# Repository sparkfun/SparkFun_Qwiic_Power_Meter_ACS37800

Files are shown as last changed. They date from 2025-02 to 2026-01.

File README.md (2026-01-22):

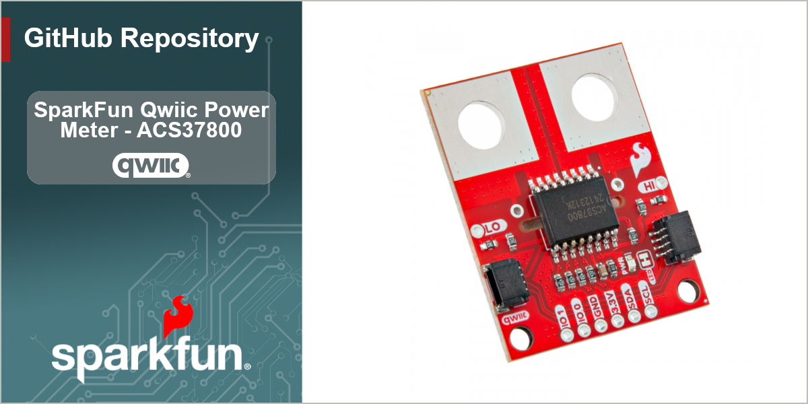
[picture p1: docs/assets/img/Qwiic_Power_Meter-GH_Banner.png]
SparkFun Qwiic Power Meter - ACS37800 (https://www.sparkfun.com/sparkfun-power-meter-acs37800-qwiic.html)


-----------------------------

The SparkFun Qwiic Power Meter - ACS37800 lets you measure voltage up to 60VDC and current up to &plusmn;30A over I<sup>2</sup>C. This board features the ACS37800 power monitor IC from Allegro Microsystems which uses a hall-effect, galvanically isolated current sensing technology to achieve reinforced isolation ratings on a small board footprint. This breakout integrates the ACS37800 into the Qwiic ecosystem to easily communicate over I<sup>2</sup>C. 

Although the ACS37800 power monitoring IC is capable of monitoring AC power at high line voltages, the SparkFun Qwiic Power Meter is designed for Safety Extra Low Voltage (SELV) applications of up to 60VDC only. Its use in AC power systems is not recommended.

Repository Contents
-------------------

* **/docs** - Hookup Guide files
* **/Hardware** - Eagle design files (.brd, .sch)
* **/Production** - Production panel files (.brd)

Documentation
--------------
* **[Library](https://github.com/sparkfun/SparkFun_ACS37800_Power_Monitor_Arduino_Library)** - Arduino library for the SparkFun Qwiic Power Meter - ACS37800.
* **[Hookup Guide](https://docs.sparkfun.com/SparkFun_Qwiic_Power_Meter_ACS37800)** - Basic hookup guide for the SparkFun Qwiic Power Meter - ACS37800.

Product Versions
----------------
* [SPX-17873](https://www.sparkfun.com/sparkx-power-meter-acs37800-qwiic.html) - Initial SparkX Release
* [SEN-29259](https://www.sparkfun.com/sparkfun-power-meter-acs37800-qwiic.html) - Initial SparkFun Release

License Information
-------------------

This product is _**open source**_! 

Please review the LICENSE.md file for license information. 

If you have any questions or concerns on licensing, please contact technical support on our [SparkFun forums](https://forum.sparkfun.com/viewforum.php?f=152).

Distributed as-is; no warranty is given.

- Your friends at SparkFun.

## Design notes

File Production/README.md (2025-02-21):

SparkFun <PRODUCT NAME> Production Files
=========================================

These are the production files SparkFun uses for printing PCBs.

License Information
-------------------
This product is open source! 

The hardware is released under [Creative Commons ShareAlike 4.0 International](https://creativecommons.org/licenses/by-sa/4.0/).

Please use, reuse, and modify these files as you see fit. Please maintain attribution to SparkFun Electronics and release anything derivative under the same license.

Distributed as-is; no warranty is given.

- Your friends at SparkFun.

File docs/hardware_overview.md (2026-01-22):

Let's take a closer look at the ACS37800 and the other hardware on the Qwiic Power Meter.

## ACS37800 Power Monitor IC

The ACS37800 power monitor IC from Allegro Microsystems is built around Allegro’s Hall-effect-based, galvanically isolated current sensing technology to achieve reinforced isolation ratings in a small PCB footprint. These features enable isolated current sensing without expensive Rogowski coils, oversized current transformers, isolated operational amplifiers, or the power loss of shunt resistors.

The ACS37800 power monitoring IC offers key power measurement parameters that can easily be accessed through its digital interface. Dedicated and configurable I/O pins for voltage/current zero crossing, undervoltage and overvoltage reporting, and fast overcurrent fault detection are available. User configuration of the IC - including its I2C address - is available through on-chip EEPROM. This breakout uses the <b>3.3V/30A</b> variant that communicates over I<sup>2</sup>C. Refer to the [datasheet](./assets/component_documentation/) for complete information about the ACS37800.

## Connectors

### Power Monitor Connections

This breakout has two large, isolated connections tied to the ACS37800's IP&plusmn; pins for connecting a voltage supply and load. The board also has smaller PTHs (plated through-holes) just below these large pads connected to IP&plusmn; if needed. 

The board routes the ACS37800's VINP and VINN to two PTHs. The ACS37800 can sense a maximum of &plusmn;250mV between VINP and VINN.

### Qwiic Connectors

The board's two Qwiic connectors route the I<sup>2</sup>C signals (SDA and SCL) along with 3.3V and Ground to both power the board and let it communicate over I<sup>2</sup>C.

### PTHs

The 0.1"-spaced PTH header on the bottom of the board routes out the ACS37800's VCC/3.3V, Ground, SDA, SCL and digital I/O pins (0 and 1). Refer to the "Configuring the DIO Pins" section in the [datasheet](./assets/component_documentation/) for more information about using these pins in I<sup>2</sup>C applications.

## LED

The sole LED on this board is a red Power LED to indicate when the board is powered on.

## Solder Jumpers

The Qwiic Power Meter has four solder jumpers labeled <b>IP+</b>, <b>I</sup>2</sup>C</b>, <b>LED</b> and <b>VINN</b>. The list below outlines their functionality, default states and notes on how to use them.

* <b>IP+</b> - This jumper connects the IP+ pin to the voltage divider on the board and is CLOSED by default. Opening this jumper isolates the "top" of the resistor divider from the IP+ power pad. Advanced users can open this jumper to measure current on the low side (and voltage from the high side).
* <b>I<sup>2</sup>C</b> - This three-way jumper pulls the SDA and SCL lines to <b>3.3V</b> through a pair of <b>4.7k&ohm;</b> resistors. It is CLOSED by default. Open the jumper to disable pullups on the I<sup>2</sup>C bus if necessary.
* <b>LED</b> - This jumper completes the circuit for the red Power LED. It is CLOSED by default. Open this jumper to disable the Power LED.
* <b>VINN</b> - This solder jumper connects the VINN pin to ground and is CLOSED by default. VINN **must** be connected to ground and this jumper should remain closed in most applications.

## Board Dimensions

The Qwiic Power Meter Breakout - ACS37800 is slightly larger than the standard Qwiic breakout and measures 1.2" x 1.5" (30.48mm x 38.10mm) with a pair of mounting holes that fit a 4-40 screw. 

<figure markdown>
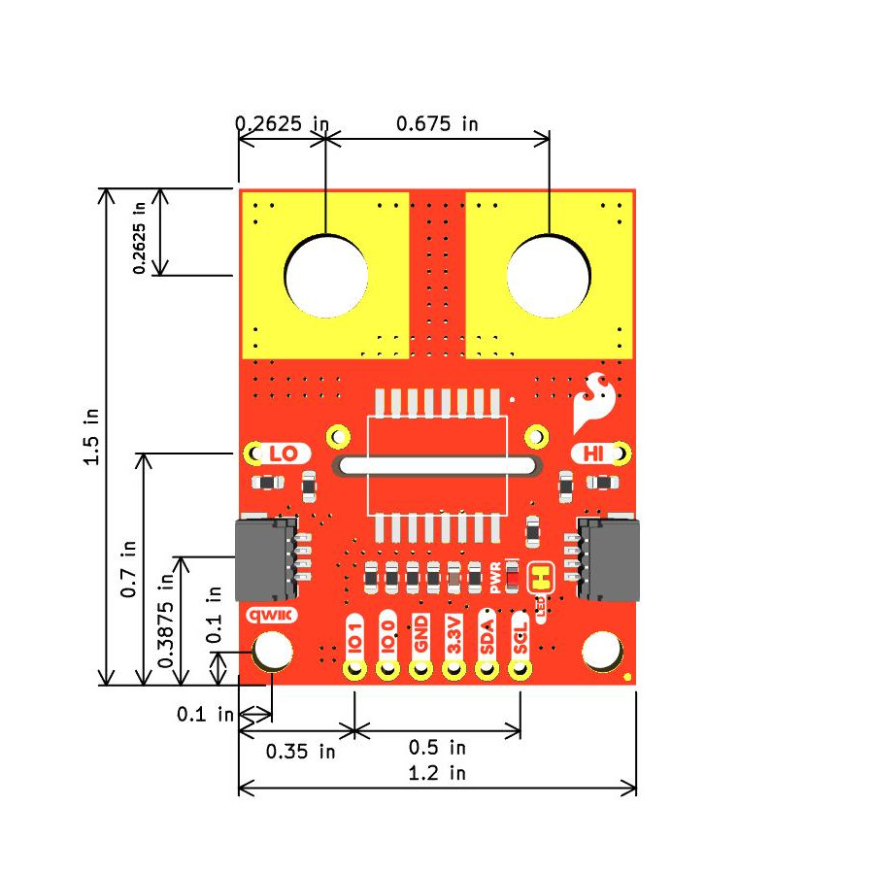
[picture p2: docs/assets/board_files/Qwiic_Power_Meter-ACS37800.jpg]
Board dimensions

</figure>

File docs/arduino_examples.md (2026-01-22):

Let's take a look at a few of the examples included in the SparkFun ACS37800 Power Monitor library.

## Example 1 - Read Voltage, Current, Power

The first example is a basic example that enables the Qwiic Power Meter and prints out measured values for voltage (Volts), current (Amps) and power (Watts). Open the example by navigating to **File** > **Examples** > **SparkFun ACS37800 Power Monitor Arduino Library** > **Example1_ReadVoltageCurrentPower**. Select your Board and Port and click the upload button. Once the code finishes compiling and uploading, open the [serial monitor](https://docs.arduino.cc/software/ide-v2/tutorials/ide-v2-serial-monitor) with the baud set to **115200** and you should see values print out every 250ms for Volts, Amps and Watts. 

If you see "ACS37800 not detected. Check connections and I2C address. Freezing..." print out, check to make sure the Qwiic Power Meter is wired correctly and properly connected to your RedBoard. If values print out as all 0's, make sure the voltage source, load and RedBoard all share a common ground.

## Example 2 - Set I<sup>2</sup>C Address

The second example shows how to adjust the ACS37800's I<sup>2</sup>C address in the IC's EEPROM. The ACS37800 accepts any valid I<sup>2</sup>C address set in the definition for `NEW_ADDRESS` in the line below:

``` c++
#define NEW_ADDRESS 0x60
```

Adjust the value for `NEW_ADDRESS` if needed and then click the "Upload" button. After the code finishes uploading, open the serial monitor with the baud set to **115200** and follow the prompts to complete the address change.

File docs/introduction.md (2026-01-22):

<figure markdown>
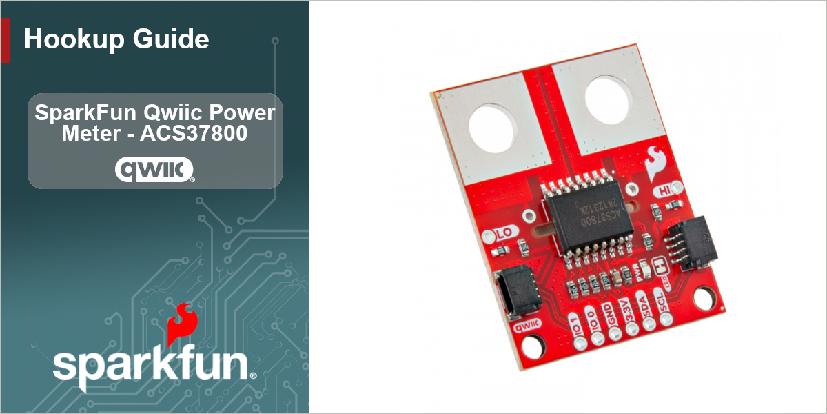
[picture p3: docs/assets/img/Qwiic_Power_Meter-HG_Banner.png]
Qwiic Power Meter Hookup Guide banner image (https://www.sparkfun.com/sparkfun-power-meter-acs37800-qwiic.html)

</figure>

The SparkFun Qwiic Power Meter - ACS37800 lets you measure voltage up to 60VDC and current up to &plusmn;30A over I<sup>2</sup>C. This board features the ACS37800 power monitor IC from Allegro Microsystems which uses a hall-effect, galvanically isolated current sensing technology to achieve reinforced isolation ratings on a small board footprint.

In order to follow along with this guide you'll need the SparkFun Qwiic Power Meter along with the following items:

* [SparkFun RedBoard IoT - ESP32](https://www.sparkfun.com/sparkfun-iot-redboard-esp32-development-board.html) (or other Arduino development board)
* [USB-C Cable](https://www.sparkfun.com/usb-a-to-usb-c-cable-1m-usb-2-0-flexible-silicone.html)
* [Qwiic Cable](https://www.sparkfun.com/flexible-qwiic-cable-100mm.html)
* A device to monitor current or voltage.

You'll also need a soldering iron and solder to wire the Qwiic Power Meter to the device you're monitoring. If you need either of those items, we have a selection of them available in our [Soldering category](https://www.sparkfun.com/tools/soldering.html).

## Topics Covered

This document contains three main sections: **Quick Start Guide**, **Hardware** and **Software**.

The Quickstart Guide assumes a working knowledge of how to assemble and use Qwiic breakouts, perform through-hole soldering, measuring current in series and using the Arduino IDE. It demonstrates how to wire up the Qwiic Power Meter to measure current in series and then jumps right into getting the necessary software packages installed to start uploading code in just a few short minutes.

The Hardware pages include a hardware overview that provides a detailed overview of the Qwiic Power Meter - ACS37800 covering all the major components on the board in detail as well as a hardware assembly page which goes over the steps required to assemble and use the board to measure current with a compatible Arduino development board.

The Software pages give instructions on how to install the SparkFun ACS37800 Arduino Library and use some of the examples included in it.

## Resources and Documentation

You'll find the board design files (KiCad files & schematic), relevant documentation (datasheets, white papers, etc.) and other helpful links in the **Resources** tab. Lastly, the **Support** pages include a Troubleshooting page that includes any helpful tips specific to this board as well as information on how to receive technical support from SparkFun.

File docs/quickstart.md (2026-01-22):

In this Quick Start guide we'll demonstrate how to assemble and use the Qwiic Power Meter to measure voltage, current and power using the SparkFun ACS37800 Power Monitor Arduino Library. This guide assumes you have an understanding of measuring current, using Qwiic breakouts and the Arduino IDE. If you're not familiar with any of these concepts we recommend reading through the Hardware and Software sections of this guide as they provide more thorough information about this Qwiic breakout and how to use it with Arduino.

## Power Monitoring Demo Assembly

### Voltage Supply and Load Assembly

We'll start by connecting the Qwiic Power Meter to our voltage supply and load. For this demo, we're using a 10 Watt power resistor to simulate the load but the concepts and circuit design can be applied to an actual power monitor circuit for something like a 3D printer or motor. Make sure to leave the load circuit powered OFF before completing the assembly to avoid damaging anything. Since we're measuring power in series we'll need to interrupt the voltage supply going to the power resistor by completing the following steps:

* Connect the the voltage supply to the IP+ pin.
* Connect the power resistor or "load" to the IP- pin.
* Connect the load to ground. In the case of this demo, we've connected the opposite side of the power resistor to the ground rail on our breadboard so we can create a common ground with the RedBoard IoT next.

<figure markdown>
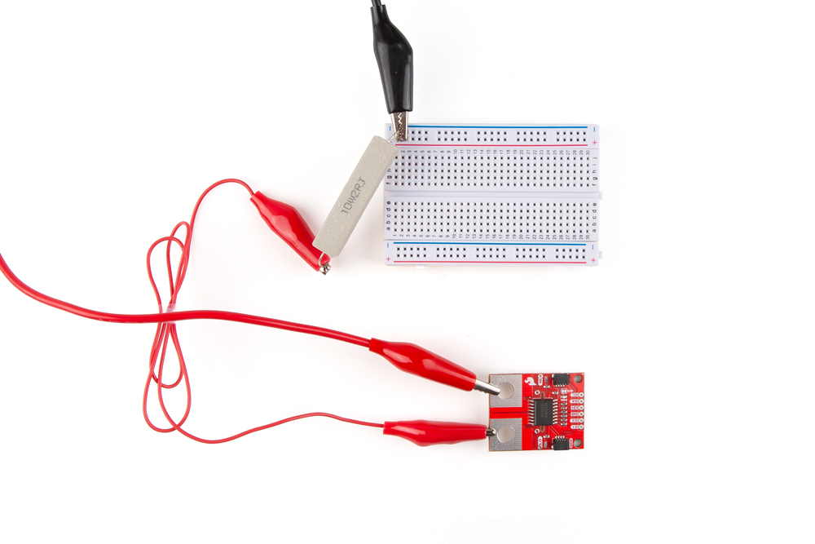
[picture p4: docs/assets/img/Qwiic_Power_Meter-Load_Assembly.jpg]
Voltage supply and load circuit assembled

</figure>

### Qwiic Assembly

Next we'll connect the Qwiic Power Meter to the RedBoard IoT - ESP32. 

* Connect the two boards together using a Qwiic cable.
* Create a connection between the grounds of the voltage source, Qwiic Power Meter and RedBoard. Since this connection is a low current path and we're using a breadboard and power resistor for this demo, we just need to connect the breadboard's ground rail to a ground pin on the RedBoard IoT using a jumper wire.
* Connect the RedBoard to a computer over USB.

The completed demo circuit should look similar to the photo below:

<figure markdown>
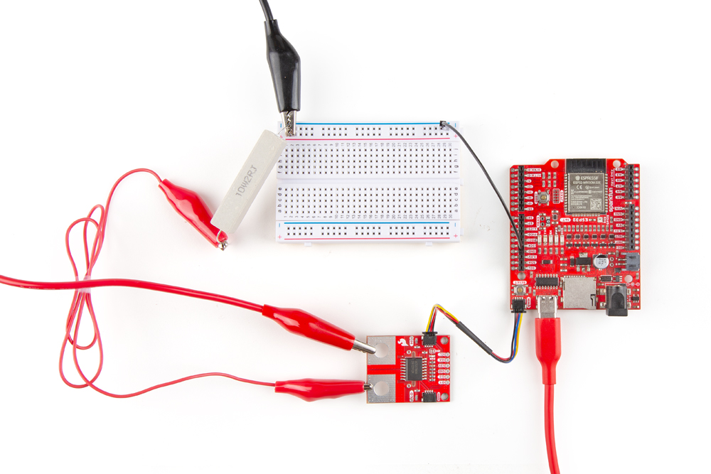
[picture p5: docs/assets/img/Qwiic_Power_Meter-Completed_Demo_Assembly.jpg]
Completed demo circuit

</figure>

## Arduino Example

With the power meter circuit built, let's move on to uploading code to monitor it.

* Install the SparkFun ACS37800 Power Monitor Arduino library using the [library manager](https://docs.arduino.cc/software/ide-v2/tutorials/ide-v2-installing-a-library/) by searching for "SparkFun ACS37800".
* If you don't already have the RedBoard IoT - ESP32 board definition installed, you'll need to install the "esp32" boards package by Espressif Systems. Copy this JSON URL: `https://espressif.github.io/arduino-esp32/package_esp32_dev_index.json` to the "Additional Boards Manager URLs" in the "Preferences" menu and then search for "esp32" in the [boards manager](https://docs.arduino.cc/software/ide-v2/tutorials/ide-v2-board-manager) tool and install the latest version of the "esp32 by Espressif Systems" boards package.
* Open Example 1 - Read Voltage Current Power.
* Select your Board and Port and click the "Upload" button.
* Once the code finishes uploading, open the serial monitor with the baud set to **15200** and you should see values for Volts, Amps and Watts print out every 250ms.

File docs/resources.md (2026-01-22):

Check out the resources below for more information about the SparkFun Qwiic Power Meter - ACS37800.

* [Schematic](./assets/board_files/Qwiic_Power_Meter-ACS37800.pdf)
* [KiCad Files](./assets/board_files/Qwiic_Power_Meter-ACS37800.zip)
* [Board Dimensions](./assets/board_files/Qwiic_Power_Meter-ACS37800.jpg)
* [Datasheet](./assets/component_documentation/ACS37800-Datasheet.pdf) (ACS37800)
* [SparkFun Arduino Library](https://github.com/sparkfun/SparkFun_ACS37800_Power_Monitor_Arduino_Library)
* [GitHub Repository](https://github.com/sparkfun/SparkFun_Qwiic_Power_Meter_ACS37800)

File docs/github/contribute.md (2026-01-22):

# Contribute: Make an Augmentation!
Spot an improvement opportunity? Feel free to contribute to our open-source design and documentation. 

## :material-file-document-multiple:&nbsp;Improve our Documentation
All of this documentation can be modified by you! Please help us make it better.

* These pages are contained in the [`docs` folder](https://github.com/sparkfun/SparkFun_Qwiic_Power_Meter_ACS37800/tree/main/docs) of the [SparkFun Qwiic Power Meter - ACS37800 repository](https://github.com/sparkfun/SparkFun_Qwiic_Power_Meter_ACS37800).

<!-- ### :material-source-pull:&nbsp;Submit a Correction -->
### Submit a Correction

1. With a GitHub account, [fork this repository](https://github.com/sparkfun/SparkFun_Qwiic_Power_Meter_ACS37800/fork).
2. Add your corrections or improvements to the markdown file.
3. File a pull request with your changes, and enjoy making the ~~words~~ ~~worlds~~ world a better place.
	* Once received, the documentation specialist will automatically be notified.
	* We will review your suggested improvements to make sure they are correct and fit within our documentation standards.

## :material-cog:&nbsp;Improve our Hardware Design
All of our designs are open-source! Please help us make it better.

* Our board design files are contained in the [`Hardware` folder](https://github.com/sparkfun/SparkFun_Qwiic_Power_Meter_ACS37800/tree/main/Hardware) of the [SparkFun Qwiic Power Meter - ACS37800 repository](https://github.com/sparkfun/SparkFun_Qwiic_Power_Meter_ACS37800).

<!-- ### :material-source-pull:&nbsp;Submit a Design Enhancement -->
### Submit a Design Enhancement

1. With a GitHub account, [fork this repository](https://github.com/sparkfun/SparkFun_Qwiic_Power_Meter_ACS37800/fork).
2. Add your design augmentation(s)
3. File a pull request with your changes, and enjoy making the ~~words~~ ~~worlds~~ world a better place.
	1. Once received, the engineer in charge of the original design will automatically be notified.
	2. We will review your suggested improvement(s) to verify that they are within our board design standards and meet our product design requirements.
	3. If approved, we will flag these changes for our next board revision. Congrats! 🍻

		!!! info
			Even if your suggestion is accepted, these changes may not be immediately available for purchase. We may have to cycle through our current product inventory first.

## Contributors&nbsp;:clap:
Let's provide some recognition to the contributors for this project!

GitHub Contributors Image
<br>


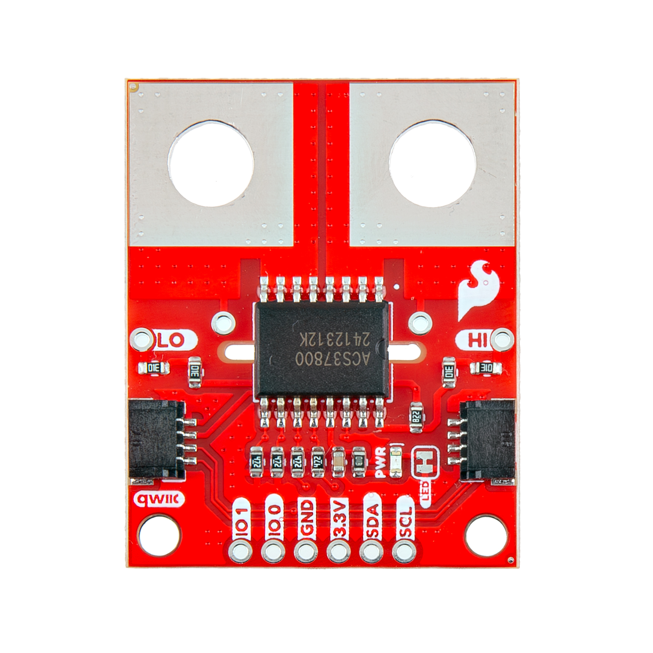
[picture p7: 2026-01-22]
docs/assets/img/Qwiic_Power_Meter-Front.jpg

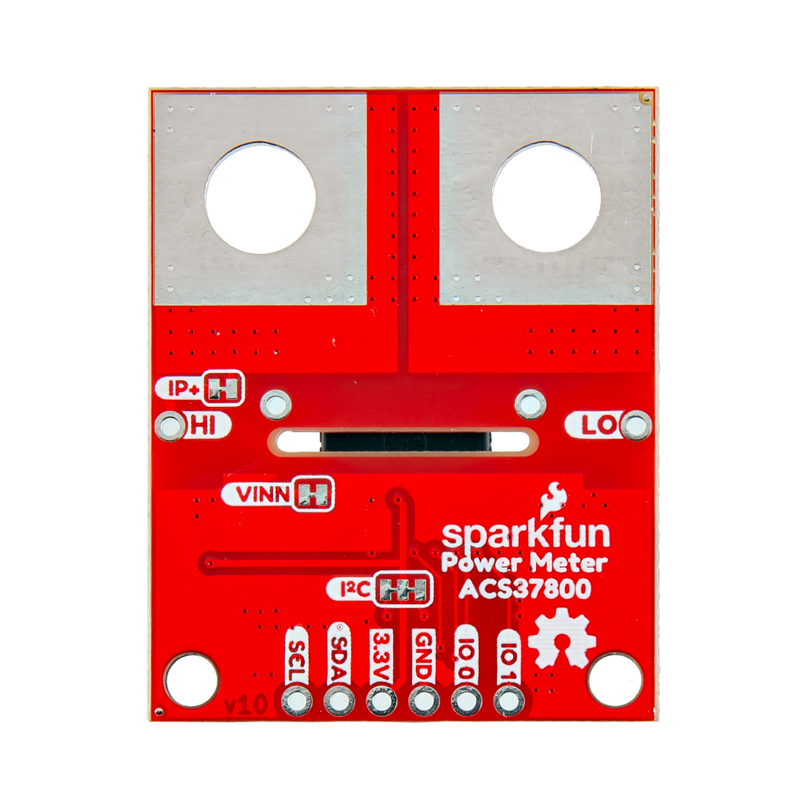
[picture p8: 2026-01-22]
docs/assets/img/Qwiic_Power_Meter-Back.jpg

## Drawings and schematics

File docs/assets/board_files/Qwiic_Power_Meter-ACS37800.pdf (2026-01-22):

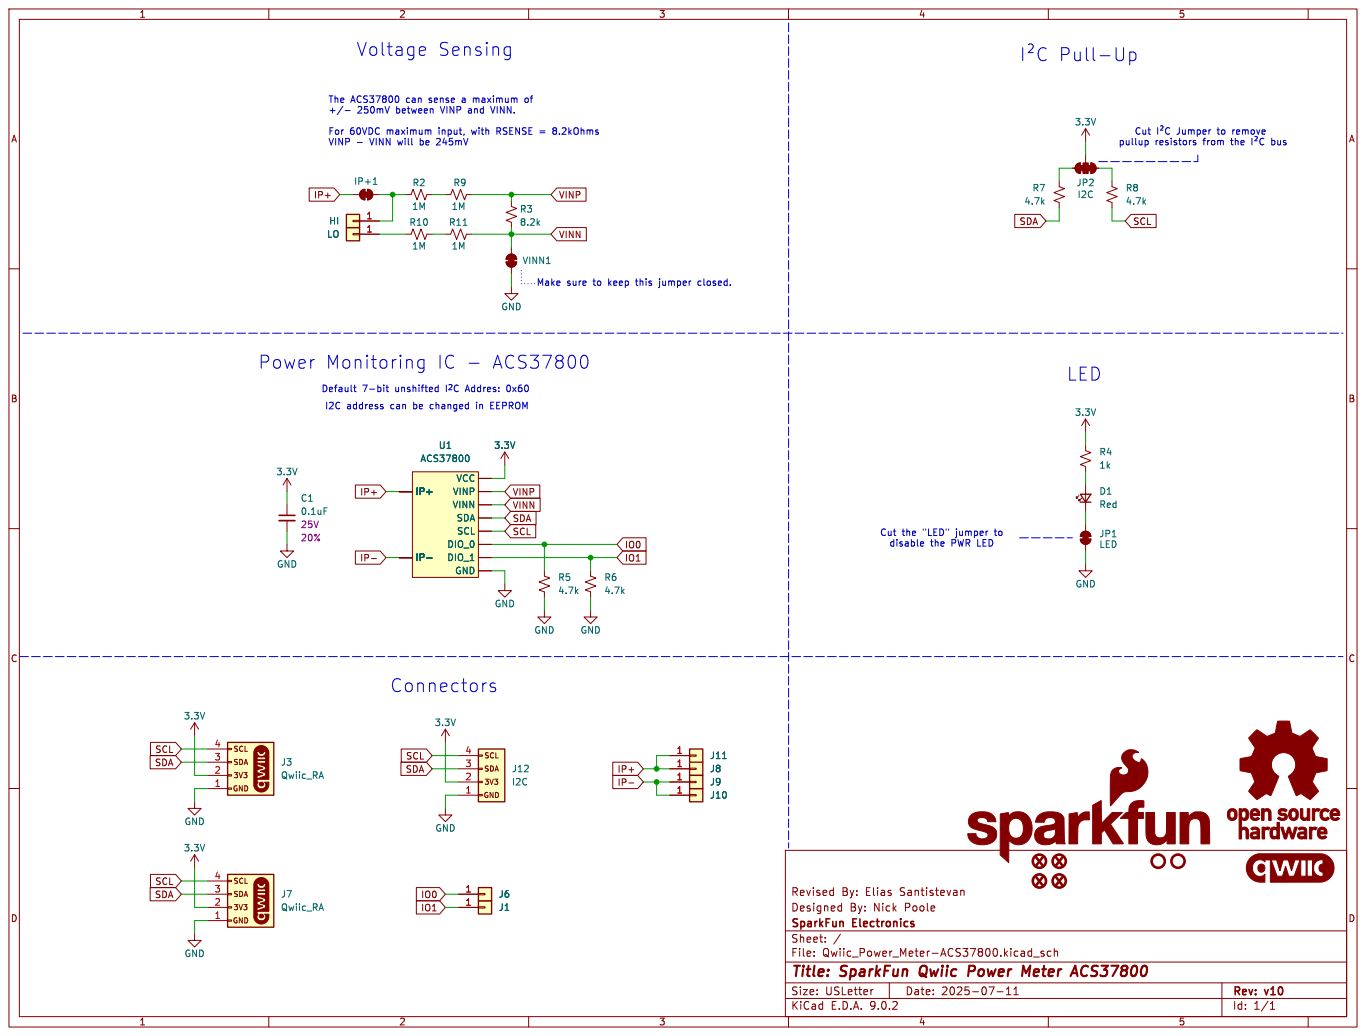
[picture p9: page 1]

disable the PWR LED Voltage Sensing

Cut þÿI²CJumper to remove

Make sure to keep this jumper closed. Connectors
J6 1 U1 ACS37800

I2C address can be changed in EEPROM

Cut the "LED" jumper to

Id: 1/1 Title: SparkFun Qwiic Power Meter ACS37800

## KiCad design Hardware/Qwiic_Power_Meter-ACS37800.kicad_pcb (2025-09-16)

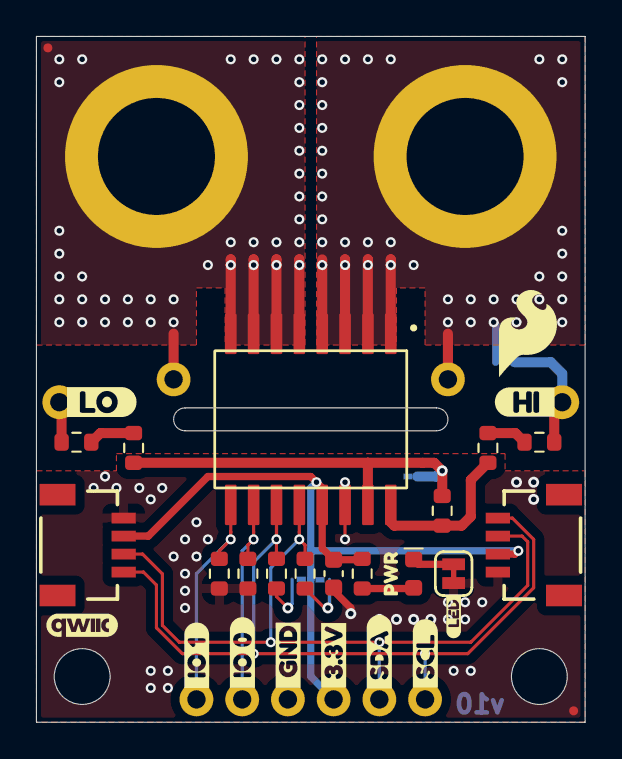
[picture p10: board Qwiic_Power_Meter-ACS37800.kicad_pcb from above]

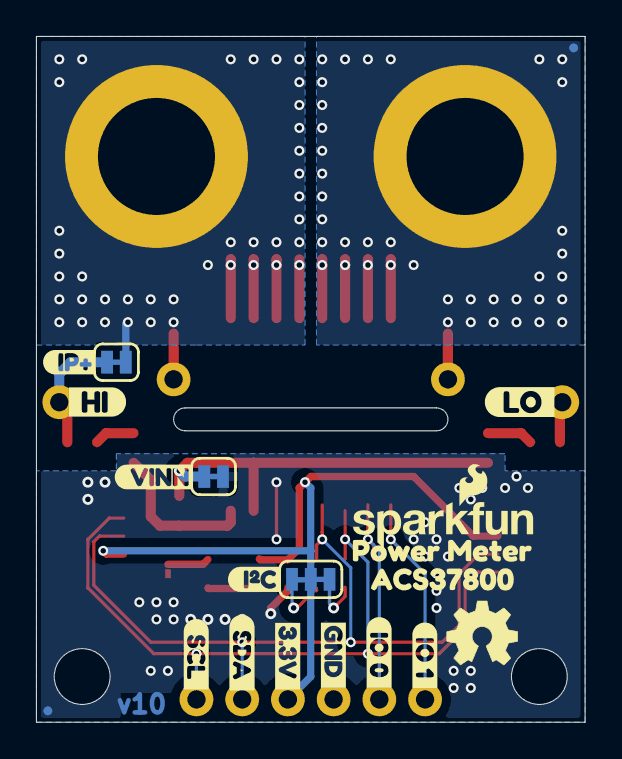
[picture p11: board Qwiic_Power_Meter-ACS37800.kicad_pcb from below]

Board: 2 copper layers, 30.5 x 38.1 mm, 59 parts (19 on the bottom side), 18 nets.

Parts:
C1: 0.1uF; C_0603_1608Metric
D1: Red; LED_0603_1608Metric_Red
FID1, FID2, FID3, FID4: Fiducial_0.5mm; Fiducial_0.5mm_Mask1mm
G1: OSHW_Logo; Creative_Commons_License
IP+1: Jumper_2_NC_Trace
J1, J4, J5, J6, J10, J11: Conn_01x01; 1x01
J3, J7: Qwiic_RA; JST_SMD_1.0mm-4_Black
J8, J9: Conn_01x01; 1x01_0.4in
J12: I2C; 1x04
JP1: LED; Jumper_2_NC_Trace
JP2: I2C; Jumper_3_NC-2_Trace
R2, R9, R10, R11: 1M; R_0603_1608Metric
R3: 8.2k; R_0603_1608Metric
R4: 1k; R_0603_1608Metric
R5, R6, R7, R8: 4.7k; R_0603_1608Metric
Ref**: Val**; OSHW_Logo_4mm
ST1, ST2: Standoff
U1: ACS37800; SO-16_Wide_Power
VINN1: Jumper_2_NC_Trace
kibuzzard-67B80BA2: G***; kibuzzard-67B80BA2
kibuzzard-68C98CE2: G***; kibuzzard-68C98CE2
kibuzzard-68C98CF7: G***; kibuzzard-68C98CF7
kibuzzard-68C98D0A: G***; kibuzzard-68C98D0A
kibuzzard-68C98D92: G***; kibuzzard-68C98D92
kibuzzard-68C98DAC: G***; kibuzzard-68C98DAC
kibuzzard-68C98DC2: G***; kibuzzard-68C98DC2
kibuzzard-68C98DD6: G***; kibuzzard-68C98DD6
kibuzzard-68C98DF7: G***; kibuzzard-68C98DF7
kibuzzard-68C98E17: G***; kibuzzard-68C98E17
kibuzzard-68C98F03: G***; kibuzzard-68C98F03
kibuzzard-68C98FF6: G***; kibuzzard-68C98FF6
kibuzzard-68C9901D: G***; kibuzzard-68C9901D
kibuzzard-68C9907C: G***; kibuzzard-68C9907C
kibuzzard-68C9913E: G***; kibuzzard-68C9913E
kibuzzard-68C9961E: G***; kibuzzard-68C9961E
kibuzzard-68C99001: G***; kibuzzard-68C99001
kibuzzard-68C99018: G***; kibuzzard-68C99018
kibuzzard-68C99023: G***; kibuzzard-68C99023
kibuzzard-68C99027: G***; kibuzzard-68C99027
kibuzzard-68C99085: G***; kibuzzard-68C99085
kibuzzard-68C99129: G***; kibuzzard-68C99129
kibuzzard-68C99652: G***; kibuzzard-68C99652

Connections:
3.3V: C1.1, J3.2, J7.2, J12.2, JP2.2 (B), R4.1, U1.13 (VCC)
GND: C1.2, J3.1, J7.1, J12.1, JP1.1 (A), R5.1, R6.1, U1.14 (GND), VINN1.2 (B)
IO0: J6.1, R5.2, U1.10 (DIO_0)
IO1: J1.1, R6.2, U1.9 (DIO_1)
IP+: IP+1.2 (B), J8.1, J11.1, U1.1 (IP+), U1.2 (IP+), U1.3 (IP+), U1.4 (IP+)
IP-: J9.1, J10.1, U1.5 (IP-), U1.6 (IP-), U1.7 (IP-), U1.8 (IP-)
unnamed: D1.2 (A), R4.2
unnamed: D1.1 (K), JP1.2 (B)
unnamed: IP+1.1 (A), J4.1, R2.1
unnamed: J5.1, R10.1
unnamed: JP2.1 (A), R8.2
unnamed: JP2.3 (C), R7.2
unnamed: R2.2, R9.1
unnamed: R10.2, R11.1
SCL: J3.4, J7.4, J12.4, R8.1, U1.11 (SCL)
SDA: J3.3, J7.3, J12.3, R7.1, U1.12 (SDA)
VINN: R3.1, R11.2, U1.15 (VINN), VINN1.1 (A)
VINP: R3.2, R9.2, U1.16 (VINP)

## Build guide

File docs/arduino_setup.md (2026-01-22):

!!! arduino
    If this is your first time using the Arduino IDE, Arduino libraries or board add-ons, we recommend reading through the following tutorials:

    - [Installing the Arduino IDE](https://learn.sparkfun.com/tutorials/installing-arduino-ide)
    - [Installing an Arduino Library](https://learn.sparkfun.com/tutorials/installing-an-arduino-library)
    - [Installing Board Definitions in the Arduino IDE](https://learn.sparkfun.com/tutorials/installing-board-definitions-in-the-arduino-ide)

## SparkFun ACS37800 Power Monitor Arduino Library

The SparkFun ACS37800 Power Monitor Arduino Library is a simple library to configure and use the ACS37800 over I<sup>2</sup>C. You can install the library with the Arduino [Library manager](https://docs.arduino.cc/software/ide-v2/tutorials/ide-v2-installing-a-library/) tool by searching for "SparkFun ACS37800". If you'd prefer a manual install, you can download a ZIP of the library [here](https://github.com/sparkfun/SparkFun_ACS37800_Power_Monitor_Arduino_Library/archive/refs/heads/main.zip).

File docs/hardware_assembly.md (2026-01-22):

Now that we're familiar with the hardware on the Qwiic Power Meter, let's hook it up in a demo circuit to measure power using a RedBoard IoT - ESP32.

## High-Side Power Measurement

### Load Circuit Assembly

* Start by connecting the the voltage supply's output to the IP+ pin.
* Connect the power resistor or "load" to the IP- pin.
* Connect the other end of the power resistor to the voltage source's ground. In the case of this demo, we've connected the opposite side of the power resistor to the ground rail on our breadboard so we can create a common ground with the RedBoard IoT next.

<figure markdown>
Voltage supply and load circuit assembled
</figure>

In this configuration, the ACS37800 is able to measure load currents up to +/- 30 Amps. The IP+ and IP- connections are electrically isolated from the rest of the circuit so, to measure voltage (and power), there needs to be a connection from the GND of the Qwiic Power Meter and RedBoard to the GND of the voltage source and load too. That connection is a low current path, only a thin wire is required, but it must be there otherwise the Qwiic Power Meter will not be able to measure voltage (and power).

### Qwiic Assembly

Next we'll connect the Qwiic Power Meter to the RedBoard IoT - ESP32. 

* **Important:** Create a common ground connection by connecting a jumper wire from the breadboard's ground rail to one of the ReBoard IoT's ground pins.
* Connect the two boards together using a Qwiic cable.
* Connect the RedBoard to a computer over USB.

The completed demo circuit should look similar to the photo below:

<figure markdown>
Completed demo circuit
</figure>

## Additional Configuration Diagrams

The above example is just one of several options for power monitoring using the Qwiic Power Meter. The following diagrams give information on wiring several together to monitor multiple devices and how to measure low-side current.

### Parallel Power Monitoring

Since the ACS37800 can be set to any valid I<sup>2</sup>C address, you can wire multiple Power Meters together to measure several loads. Wiring multiple Qwiic Power Meters in parallel with the voltage source connected to the IP+ on each board with an individual load connected to the IP- pins measures the same voltage across all boards with individual load current and power:

<figure markdown>
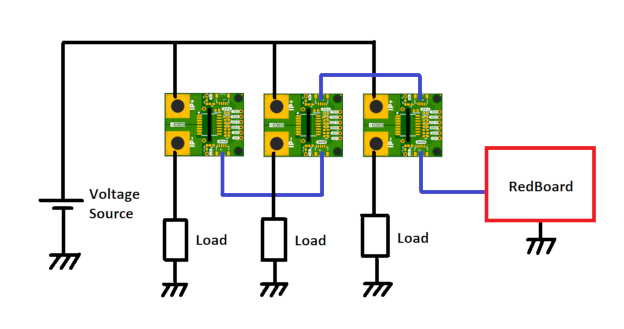
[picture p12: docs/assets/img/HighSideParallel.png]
Wiring diagram for measuring multiple load current/power with a single supply voltage.

</figure>

### Series Power Monitoring

!!! "Important Note"
    Be careful that the Qwiic Power Meter GND connection does not accidentally become a current path which shorts out part of the power circuit. Think very carefully before connecting a jumper wire from GND to an intermediate voltage in a multi-cell, multi-photovoltaic panel or multi-load system. Do not do this:

<figure markdown>
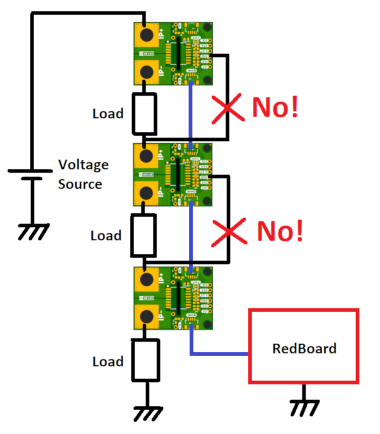
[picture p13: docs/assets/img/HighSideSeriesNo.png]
Incorrect series wiring diagram.
[]
</figure>

### Low-Side Current Measurement

The Qwiic Power Meter can be connected into the low-side of a power circuit too. However, when connected like this, it is only able to measure current, not voltage or power. (Advanced users can: cut the IP+ split-pad jumper link on the rear of the board; and then connect the HI breakout pad to the high side of the load. Consult the [schematic](./assets/board_files/Qwiic_Power_Meter-ACS37800.pdf) and [datasheet](./assets/component_documentation/ACS37800-Datasheet.pdf) for more details.)

<figure markdown>
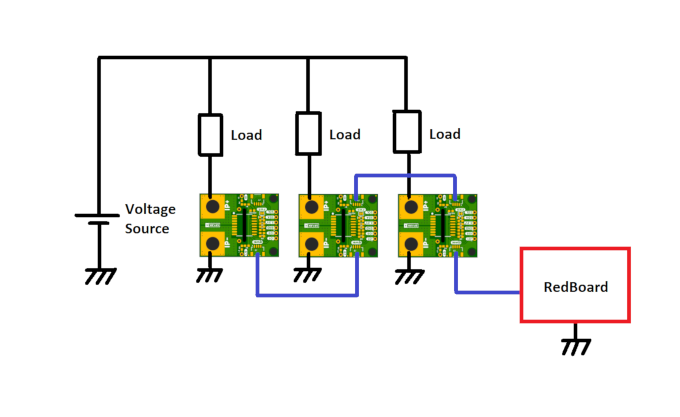
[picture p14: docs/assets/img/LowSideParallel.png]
Wiring diagram for parallel low-side current measurement

</figure>

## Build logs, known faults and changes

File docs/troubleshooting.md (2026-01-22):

## Safety Information

Although the ACS37800 power monitoring IC is capable of monitoring AC power at high line voltages, the SparkFun Power Meter is designed for Safety Extra Low Voltage (SELV) applications of up to 60VDC only. Its use in AC power systems is not recommended or condoned.

## Wiring Multiple Current Sensors

Be careful that the Qwiic Power Meter GND connection does not accidentally become a current path which shorts out part of the power circuit. Think very carefully before connecting a jumper wire from GND to an intermediate voltage in a multi-cell, multi-photovoltaic panel or multi-load system. Do not do this:

<figure markdown>
Wiring diagram for incorrect wiring of multiple Power Meters in series
</figure>

## General Troubleshooting

!!! note
    <span class="glyphicon glyphicon-question-sign" aria-hidden="true"></span>
        <strong> Not working as expected and need help? </strong> <br /><br />

    If you need technical assistance and more information on a product that is not working as you expected, we recommend heading on over to the <a href="https://community.sparkfun.com/">SparkFun Forums</a> to get help from our Technical Support team and community. If this is your first visit, you'll need to create a forum account to search product forums and post questions.<br /><br />

    <div style="text-align: center"><a href="https://community.sparkfun.com/" class="md-button md-button--primary">Log Into SparkFun Forums</a></div>

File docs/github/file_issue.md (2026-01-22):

# Did we make a mistake?

Spot something wrong? Please let us know. 

## Discrepancies in the Documentation

All of our documentation can be modified by you! Please help us make it better.

* The documentation files for these pages are contained in the [`docs` folder](https://github.com/sparkfun/SparkFun_Qwiic_Power_Meter_ACS37800/tree/main/docs) of the [SparkFun Qwiic Power Meter - ACS37800 repository](https://github.com/sparkfun/SparkFun_Qwiic_Power_Meter_ACS37800).

### 🔍 Spot something wrong?

If a section of the documentation is incorrect, please [open an issue](https://github.com/sparkfun/SparkFun_Qwiic_Power_Meter_ACS37800/issues) and let us know.

### Do you have a suggested correction?

1. With a GitHub account, [fork this repository](https://github.com/sparkfun/SparkFun_Qwiic_Power_Meter_ACS37800/fork).
2. Add your correction(s) or improvement(s) to the markdown file(s)
3. File a pull request with your changes, and enjoy making the ~~words~~ ~~worlds~~ world a better place.
	* Once received, the documentation specialist will automatically be notified.
	* We will review your suggested improvement(s) to make sure they are correct and fit within our documentation standards.

## Problems in the Hardware Design

All of our designs are open-source! Please help us make it better.

* Our board design files are contained in the [`Hardware` folder](https://github.com/sparkfun/SparkFun_Qwiic_Power_Meter_ACS37800/tree/main/Hardware) of the [SparkFun Qwiic Power Meter - ACS37800 repository](https://github.com/sparkfun/SparkFun_Qwiic_Power_Meter_ACS37800).

### Does something not make sense? 🤔

If part of the design is confusing, please [open an issue](https://github.com/sparkfun/SparkFun_Qwiic_Power_Meter_ACS37800/issues) and let us know.

### Did we forget to include an important function of the board? 🤦

If part of the board's functionality is missing, please [open an issue](https://github.com/sparkfun/SparkFun_Qwiic_Power_Meter_ACS37800/issues) and file a feature request.

!!! tip "Design Considerations"
	Please keep in mind that we may intentionally exclude certain functions of the board to meet our product design requirements.
	
	* *For example, our Qwiic Micro boards are intended to fit on a small board layout and only use I<sup>2</sup>C communication; therefore, we may not have the SPI and interrupt pins available for users.*

### Do you wish to contribute directly to improving the board design?

1. With a GitHub account, [fork this repository](https://github.com/sparkfun/SparkFun_Qwiic_Power_Meter_ACS37800/fork).
2. Add your design augmentation(s)
3. File a pull request with your changes, and enjoy making the ~~words~~ ~~worlds~~ world a better place.
	1. Once received, the engineer in charge of the original design will automatically be notified.
	2. We will review your suggested improvement(s) to verify that they are within our board design standards and meet our product design requirements.
	3. If approved, we will flag these changes for our next board revision. Congrats! 🍻

		!!! info
			Even if your suggestion is accepted, these changes may not be immediately available for purchase. We may have to cycle through our current product inventory first.

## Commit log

2025-02-21 v10 ready for review
    [Qwiic_Power_Meter-ACS37800.kicad_pcb, Qwiic_Power_Meter-ACS37800.kicad_sch]
2025-02-22 Add missing fiducials
    [Qwiic_Power_Meter-ACS37800.kicad_pcb]
2025-02-24 Update SOIC Wide footprint
    [Qwiic_Power_Meter-ACS37800.kicad_pcb, Qwiic_Power_Meter-ACS37800.kicad_sch]
2025-02-24 Update 0.4in symbol and FP
    [Qwiic_Power_Meter-ACS37800.kicad_sch]
2025-04-30 Saved in KiCad 9
    [Qwiic_Power_Meter-ACS37800.kicad_pcb, Qwiic_Power_Meter-ACS37800.kicad_sch]
2025-04-30 Adds measures, labels LED jumper, updates some schematic text
    [Qwiic_Power_Meter-ACS37800.kicad_pcb, Qwiic_Power_Meter-ACS37800.kicad_sch]
2025-04-30 Add missed measure
    [Qwiic_Power_Meter-ACS37800.kicad_pcb]
2025-04-30 Makes design 2-layer, updates jumper names in schematic
    [Qwiic_Power_Meter-ACS37800.kicad_sch]
2025-06-25 Fixes some missing traces
    [Qwiic_Power_Meter-ACS37800.kicad_pcb, Qwiic_Power_Meter-ACS37800.kicad_sch]
2025-07-11 Adds ordering instructions, updates design by, revised by
    [Qwiic_Power_Meter-ACS37800.kicad_pcb, Qwiic_Power_Meter-ACS37800.kicad_sch]
2025-07-11 Adds some more notes to the design
    [Qwiic_Power_Meter-ACS37800.kicad_pcb, Qwiic_Power_Meter-ACS37800.kicad_sch]
2025-09-16 Fixes silk
    [Qwiic_Power_Meter-ACS37800.kicad_pcb]
2025-09-16 Adds fiducials and standoffs, changes the silk on the underside
    [Qwiic_Power_Meter-ACS37800.kicad_pcb, Qwiic_Power_Meter-ACS37800.kicad_sch]
2025-09-16 Adds some measures
    [Qwiic_Power_Meter-ACS37800.kicad_pcb]
2026-01-20 Updates 1x01 labels in the schematic, fixes some jumper labels
    [Qwiic_Power_Meter-ACS37800.kicad_sch]
2026-01-22 Docs update
    Updating board files and adding GH pages build file.

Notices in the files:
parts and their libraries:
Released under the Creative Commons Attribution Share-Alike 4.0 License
